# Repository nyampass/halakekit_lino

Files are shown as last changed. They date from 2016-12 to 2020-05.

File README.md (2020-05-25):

# HaLakeKitLino
A BLE module.

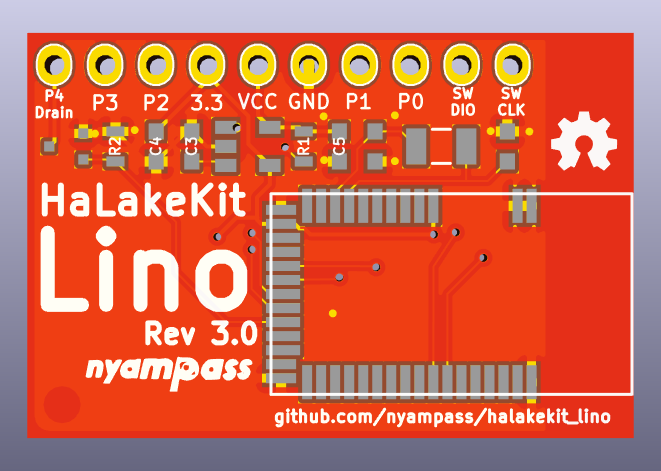
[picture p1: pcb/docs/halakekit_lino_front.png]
HaLakeKitLino image


# PCB
## Software
This PCB was designed on KiCad.

## components
- [MDBT40](http://www.tinyosshop.com/index.php?route=product/product&product_id=970)
- [NJM287033](http://akizukidenshi.com/catalog/g/gI-10393/)
- [RTF015N03](http://akizukidenshi.com/catalog/g/gI-05959/)
- [BAT-HLD-001](http://www.digikey.jp/product-detail/ja/linx-technologies-inc/BAT-HLD-001-TR/BAT-HLD-001-TRCT-ND/5803803)
- [32.7Hz cristal](http://akizukidenshi.com/catalog/g/gP-07195/)
- 4.7uf condensor
- 0.1uf condensor
- 0.01uf condensor
- 12pf condensor * 2
- 1K resister * 2

Size of chip condensors and resisters are all 0603.

# License
MIT

# References
- [BLE nano](http://redbearlab.com/blenano/)
- [BLE nano schematic](https://github.com/RedBearLab/BLENano/tree/master/PCB)
- [KiCAD_Libraries/PCB/RF_Modules.pretty/MDBT40.kicad_mod](https://github.com/CascoLogix/KiCAD_Libraries/blob/master/PCB/RF_Modules.pretty/MDBT40.kicad_mod)

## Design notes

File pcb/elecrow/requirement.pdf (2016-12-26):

Please mount BCM20737S with this side.

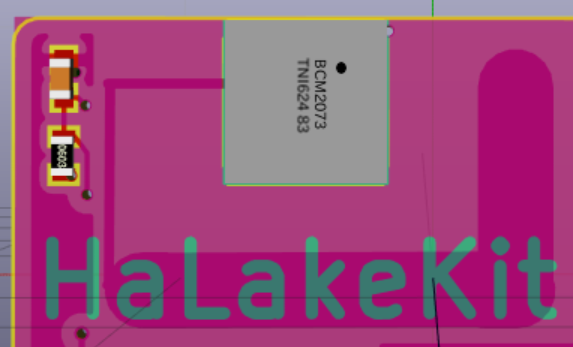
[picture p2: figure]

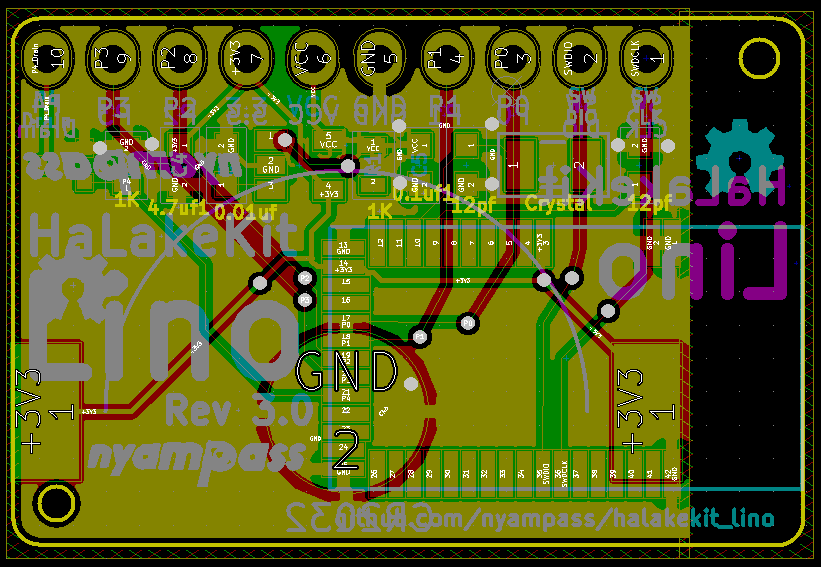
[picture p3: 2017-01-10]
pcb/docs/layers.png

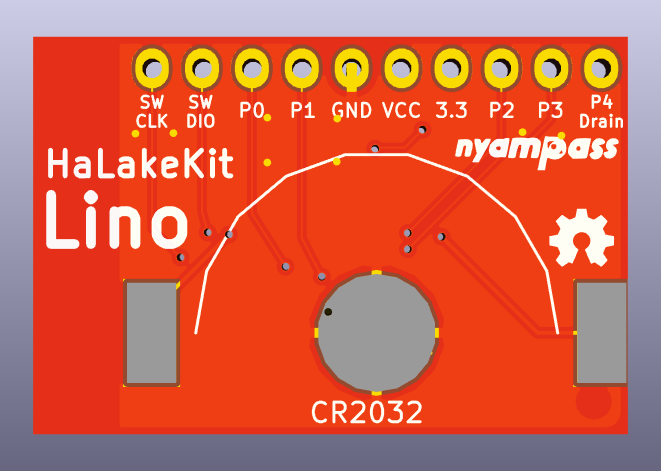
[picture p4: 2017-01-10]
pcb/docs/halakekit_lino_back.png

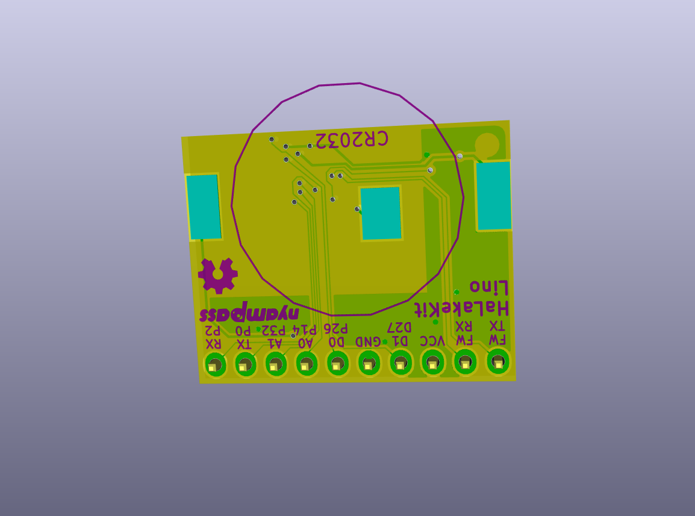
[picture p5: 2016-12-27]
pcb/halakekit_lino.png

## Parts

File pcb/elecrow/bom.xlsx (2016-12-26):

HaLakeKit Lino BOM
Elecrow PN | Parts | Value | Package | QTY | Digikey/Mouser/Manufacturer Part | Remark/ Link
2013501A | C | 100uF | C0603 | 1 | -
5042090A | R | 10K | C0603 | 1 | -
 | U1 | BCM20737S | 48-TFBGA | 1 | we want to use our stocks. | http://www.cypress.com/file/299481/download

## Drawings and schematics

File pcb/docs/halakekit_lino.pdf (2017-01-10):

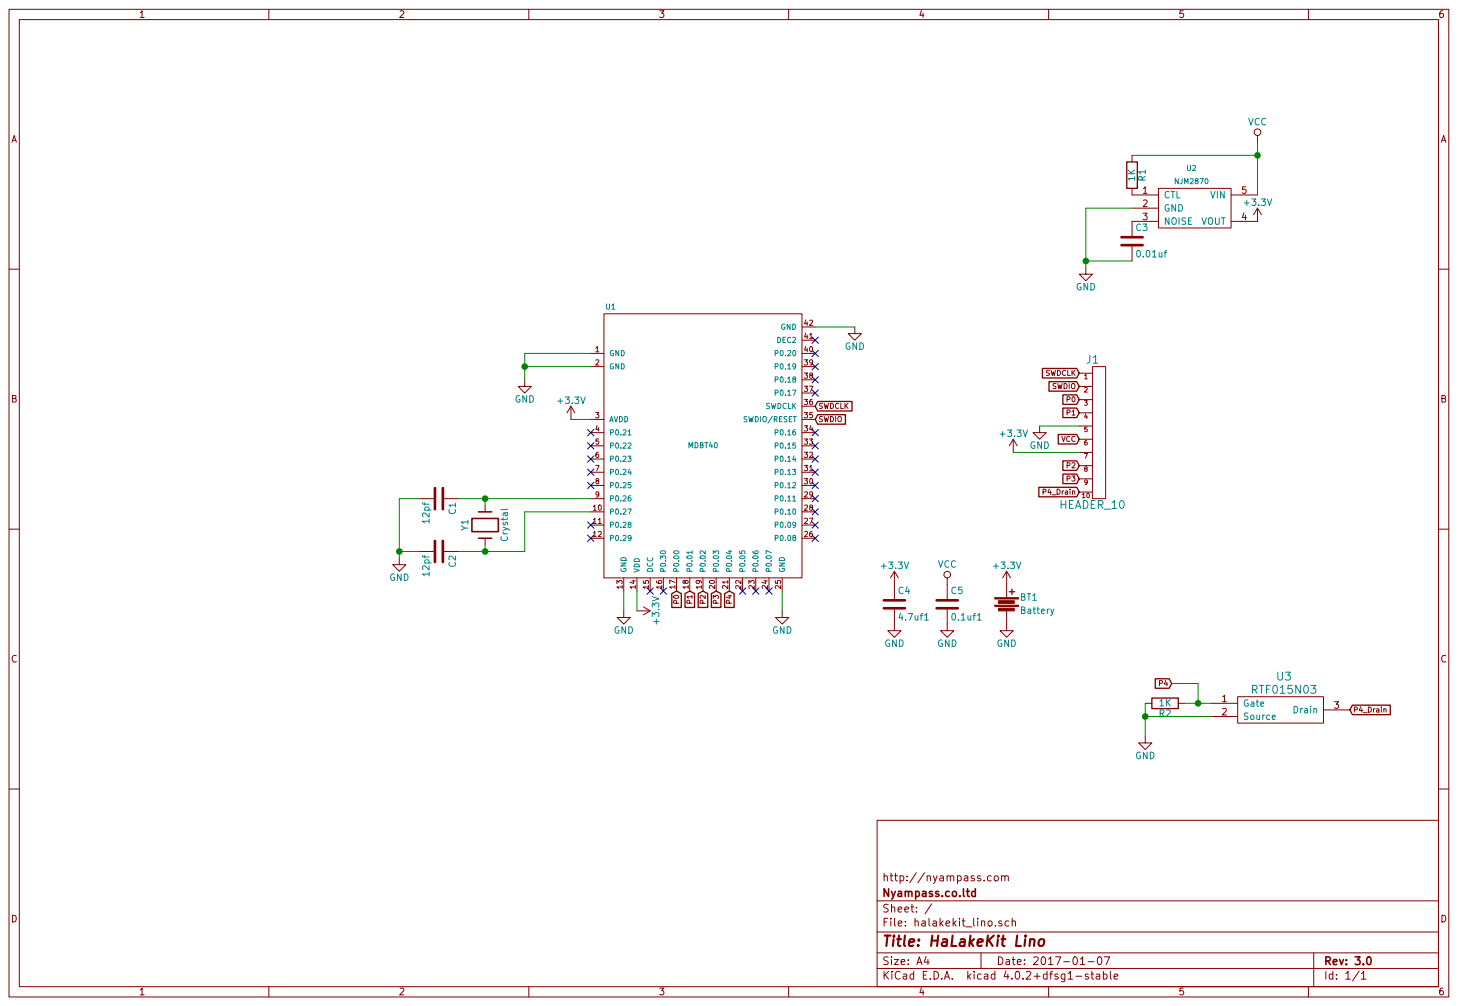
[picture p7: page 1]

http://nyampass.com
File: halakekit_lino.sch Sheet: / Nyampass.co.ltd

Id: 1/1 Title: HaLakeKit Lino

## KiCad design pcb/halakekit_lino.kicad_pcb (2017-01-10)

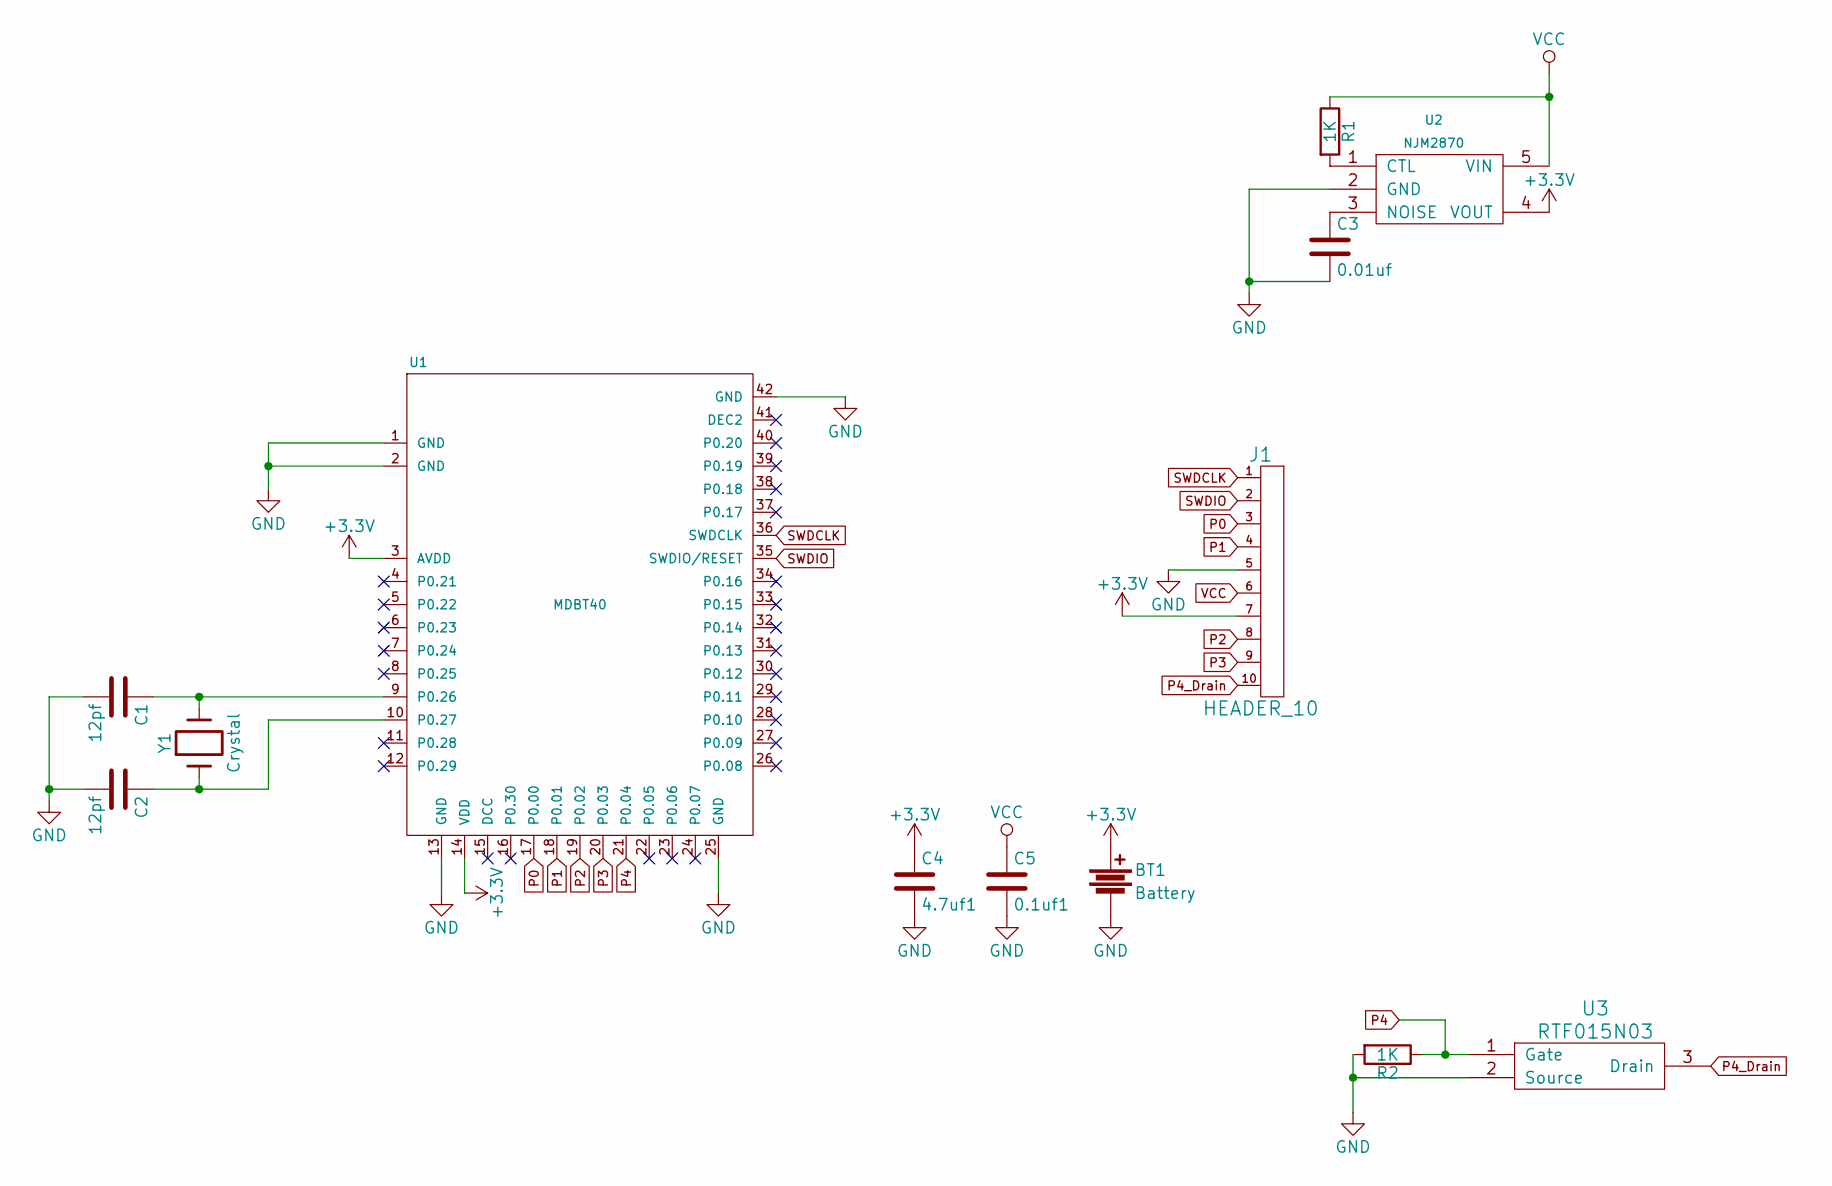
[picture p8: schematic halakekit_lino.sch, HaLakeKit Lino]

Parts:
BT1: Battery; BAT-HLD-001-TRCT
C1, C2: 12pf; C_0603
C3: 0.01uf; C_0603
C4: 4.7uf1; C_0603
C5: 0.1uf1; C_0603
J1: HEADER_10; Pin_Header_Straight_1x10
R1, R2: 1K; R_0603
U1: MDBT40
U2: NJM2870; SOT-23-5
U3: RTF015N03; rtf015n03
Y1: Crystal; FC-135

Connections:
+3V3: BT1.1, C4.1, J1.7, U1.3 (AVDD), U1.14 (VDD), U2.4 (VOUT)
GND: BT1.2, C1.2, C2.2, C3.2, C4.2, C5.2, J1.5, R2.2, U1.1 (GND), U1.2 (GND), U1.13 (GND), U1.25 (GND), U1.42 (GND), U2.2 (GND), U3.2 (Source)
unnamed: C1.1, U1.9 (P0.26), Y1.2
unnamed: C2.1, U1.10 (P0.27), Y1.1
unnamed: C3.1, U2.3 (NOISE)
unnamed: R1.2, U2.1 (CTL)
P0: J1.3, U1.17 (P0.00)
P1: J1.4, U1.18 (P0.01)
P2: J1.8, U1.19 (P0.02)
P3: J1.9, U1.20 (P0.03)
P4: R2.1, U1.21 (P0.04), U3.1 (Gate)
P4_Drain: J1.10, U3.3 (Drain)
SWDCLK: J1.1, U1.36 (SWDCLK)
SWDIO: J1.2, U1.35 (SWDIO/RESET)
VCC: C5.1, J1.6, R1.1, U2.5 (VIN)

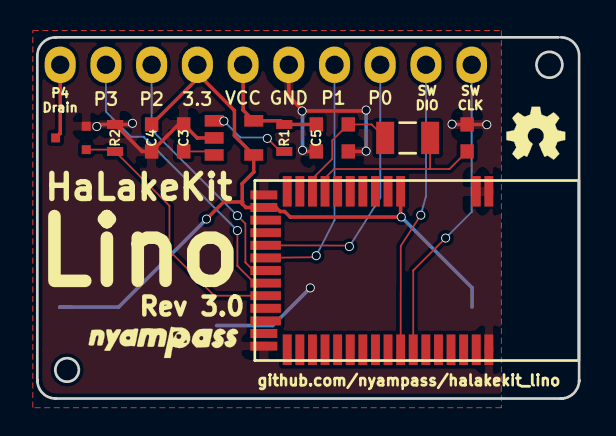
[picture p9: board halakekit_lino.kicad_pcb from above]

Board: 2 copper layers, 30.1 x 20.1 mm, 13 parts (1 on the bottom side), 15 nets.

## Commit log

2016-12-08 Updated to ver1.1
    [halakekit_lino.kicad_pcb]
2016-12-26 Add files to order PCBA for elecrow
    [bom.xlsx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]
2016-12-27 Change board layout as rev 1.2
    [halakekit_lino.kicad_pcb, halakekit_lino.sch]
2016-12-27 Update plot data to order Rev2.0 PCB
    [halakekit_lino-B.Cu.gbl, halakekit_lino-B.Mask.gbs, halakekit_lino-B.SilkS.gbo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]
2017-01-09 Create net data with using MDBT40
    [halakekit_lino.kicad_pcb, halakekit_lino.sch]
2017-01-09 Update pcb to rev3.0
    [halakekit_lino.kicad_pcb, halakekit_lino.sch]
2017-01-10 Change url on pcb
    [halakekit_lino.kicad_pcb]
2017-01-10 Created pcb directory
    [bom.xlsx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]
2017-01-10 Update plot files to order
    [halakekit_lino_order.kicad_pcb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]
2017-01-11 Add links for pcb components on readme
2020-05-25 Correct typo about resister
